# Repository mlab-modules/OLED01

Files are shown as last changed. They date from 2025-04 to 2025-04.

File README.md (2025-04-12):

# OLED01 - OLED Display Touchscreen with I2C interface

The OLED01 is an MLAB module, designed for using OLED displays, specifically the [EA OLEDM128-6GGA](https://www.lcd-module.com/fileadmin/eng/pdf/grafik/oledm128-6e.pdf) built around the [SSD1306](https://cdn-shop.adafruit.com/datasheets/SSD1306.pdf) controller, this module communicates using the I2C protocol. The module's design uses standard MLAB headers and an internal 12V power supply, for powering the OLED display. This  module provides a solution for integrating high-contrast OLED displays into various systems.

An important feature of the OLED01 module is the integrated I2C level converter, which can operate within a 3-5V power supply and signal range. The OLED01 also incorporates a pair of LEDs and a buzzer, driven by an integrated transistor and it is equipped with a reset circuit to ensure proper clear display initialization after power-up.

## Design
OLED01 OLED01

The OLED01 module is designed to promote user-friendly integration and durability. Its compact form factor allows for easy placement within diverse hardware configurations, and the robust construction assures longevity. The contained OLED display delivers a resolution of 128x64 pixels with high-contrast visual output.

### Touchscreen Support

The OLED01 module supports 4-wire resistive touchscreens through integration with the [TSC2007 touch controller](https://www.ti.com/lit/ds/symlink/tsc2007.pdf). This I2C-based controller enables position and pressure detection with 12-bit resolution, low power consumption, and internal preprocessing for noise reduction. The PENIRQ output allows interrupt-based touch event detection.

This expands the module's usability for interactive user interfaces in embedded systems.

## Specifications

- **Interface**: I2C
- **Touchscreen Support**: 4-wire resistive touchscreen interface via TSC2007 (I2C, 12-bit ADC)
- **Power Supply**: 3-5V operational range for I2C, Internal 12V supply for OLED
- **Display**: 128x64 pixels resolution
- **Additional Features**: Pair of LEDs and buzzer driven by integrated transistor by external GPIO
- **Reset Circuit**: Included for proper initialization of the OLED display

## Possible Applications

The OLED01 module's versatility allows for use in a wide range of applications:

2. **Industrial Control Systems:** The robustness and clarity of the OLED display, coupled with the additional buzzer and LED indicators, make this module a top choice for control panels in industrial machinery and robotics.
3. **Automotive Systems:** The OLED01 can serve as an interface for vehicle systems, providing clear and sharp visual output under various lighting conditions.
5. **Experimental Projects and Prototyping:** The module's easy integration through MLAB headers and broad compatibility with the I2C interface make it suitable for experimental electronics projects, prototyping, and educational applications.

## Schematics
Schematics

## Usage examples

  * [Li-ion-Charger](https://github.com/MLAB-project/Li-ion-Charger)

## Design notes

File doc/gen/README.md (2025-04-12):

# PCB

Board size: 60.76x70.92 mm (2.39x2.79 inches)

- This is the size of the rectangle that contains the board
- Thickness: 1.6 mm (63 mils)
- Material: FR4
- Finish: None
- Layers: 2
- Copper thickness: 35 µm

Solder mask: TOP / BOTTOM

- Color: Green

Silk screen: TOP / BOTTOM

- Color: White

Stackup:

| Name | Type | Color | Thickness [µm]| Material | Er | Loss tan |
|---|---|---|---|---|---|---|
| F.SilkS | Top Silk Screen | | | | | |
| F.Paste | Top Solder Paste | | | | | |
| F.Mask | Top Solder Mask | Green | 10 | | | |
| F.Cu | copper | | 35 | | | |
| dielectric 1 | core | | 1510 | FR4 | 4.5 | 0.020 |
| B.Cu | copper | | 35 | | | |
| B.Mask | Bottom Solder Mask | Green | 10 | | | |
| B.Paste | Bottom Solder Paste  | | | | | |
| B.SilkS | Bottom Silk Screen | | | | | |

# Important sizes

Clearance: 0.2 mm (8 mils)

Track width: 0.4 mm (16 mils)

- By design rules: 0.2 mm (8 mils)

Drill: 0.5 mm (20 mils)

- Vias: 0.5 mm (20 mils) [Design: 0.4 mm (16 mils)]
- Pads: 1.0 mm (39 mils)
- The above values are real drill sizes, they add 0.1 mm (4 mils) to plated holes (PTH)

Via: 0.8/0.4 mm (31/16 mils)

- By design rules: 0.4/0.3 mm (16/12 mils)
- Micro via: yes [0.2/0.1 mm (8/4 mils)]
- Buried/blind via: yes
- Total: 54 (thru: 54 buried/blind: 0 micro: 0)

Outer Annular Ring: 0.15 mm (6 mils)

- By design rules: 0.26 mm (10 mils)

Eurocircuits class: 4B
- Using min drill 0.5 mm for an OAR of 0.15 mm

# General stats

Components count: (SMD/THT)

- Top: 0/10 (THT)
- Bottom: 43/1 (SMD + THT)

Defined tracks:

- 0.2 mm (8 mils)
- 0.3 mm (12 mils)
- 0.4 mm (16 mils)
- 0.5 mm (20 mils)

Used tracks:

- 0.4 mm (16 mils) (237) defined: yes
- 0.5 mm (20 mils) (9) defined: yes
- 0.6 mm (24 mils) (24) defined: no
- 1.0 mm (39 mils) (6) defined: no
- 1.1 mm (43 mils) (3) defined: no

Defined vias:

Used vias:

- 0.8/0.4 mm (31/16 mils) (Count: 54, Aspect: 2.0 A) defined: no

Holes (excluding vias):

- 0.89 mm (35 mils) (55)
- 3.0 mm (118 mils) (4)

Oval holes:

Drill tools (including vias and computing adjusts and rounding):

- 0.5 mm (20 mils) (54)
- 1.0 mm (39 mils) (55)
- 3.1 mm (122 mils) (4)

Solder paste stats:

Using a paste with 87.75 % alloy, that has an specific gravity for the alloy of 7.4 g/cm³
and 1.0 g/cm³ for the flux. This paste has an specific gravity of  4.15 g/cm³.

The stencil thickness is  0.12 mm.

| Side | Pads with paste | Area [mm²] | Paste [g] |
|---|---|---|---|
| Total  | 125 | 204.41 | 1.02 |

Note: this is just an approximation to the theoretical value. Margins of the solder mask and waste aren't computed.

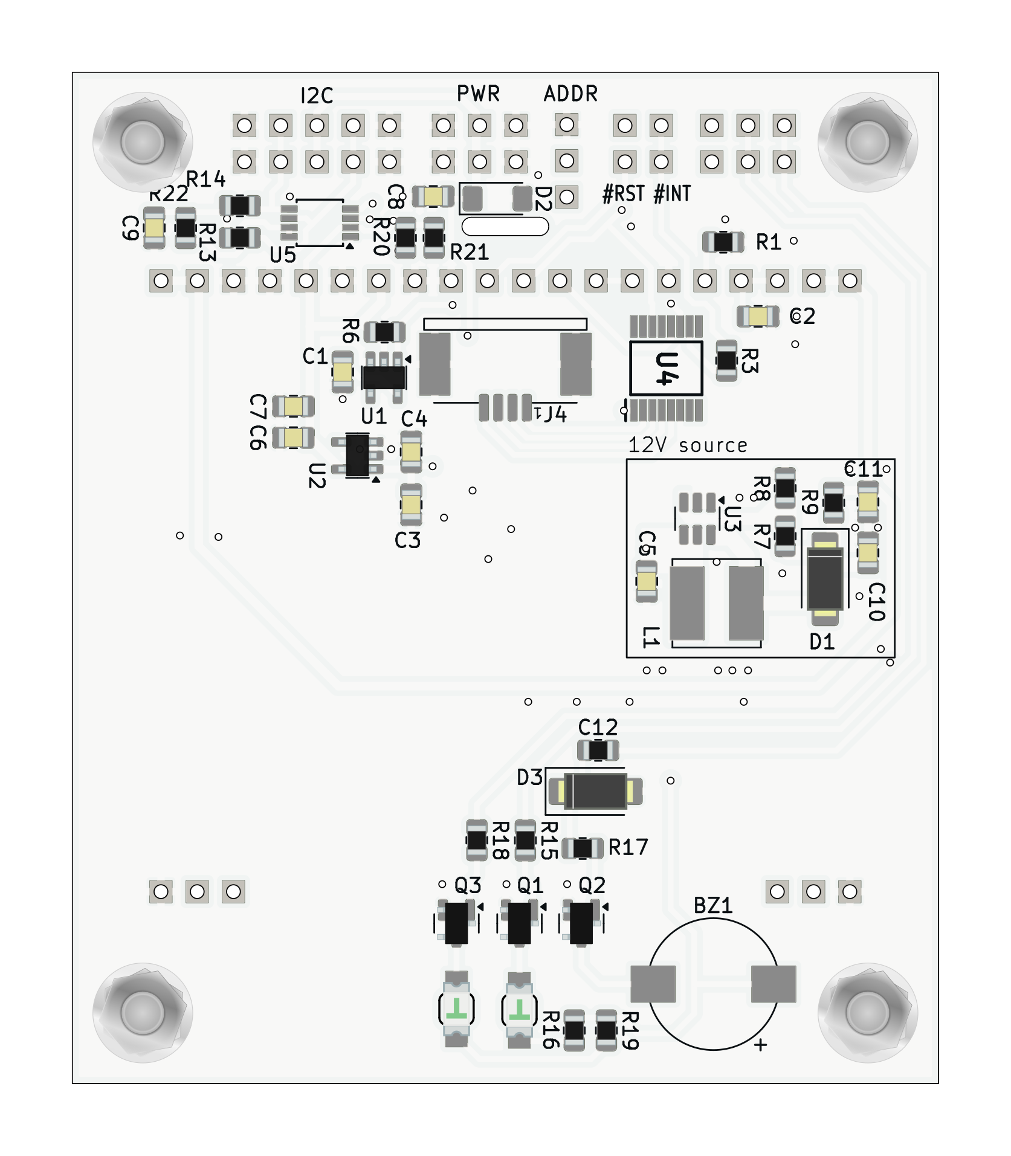
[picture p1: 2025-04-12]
doc/gen/img/OLED01-bottom.png

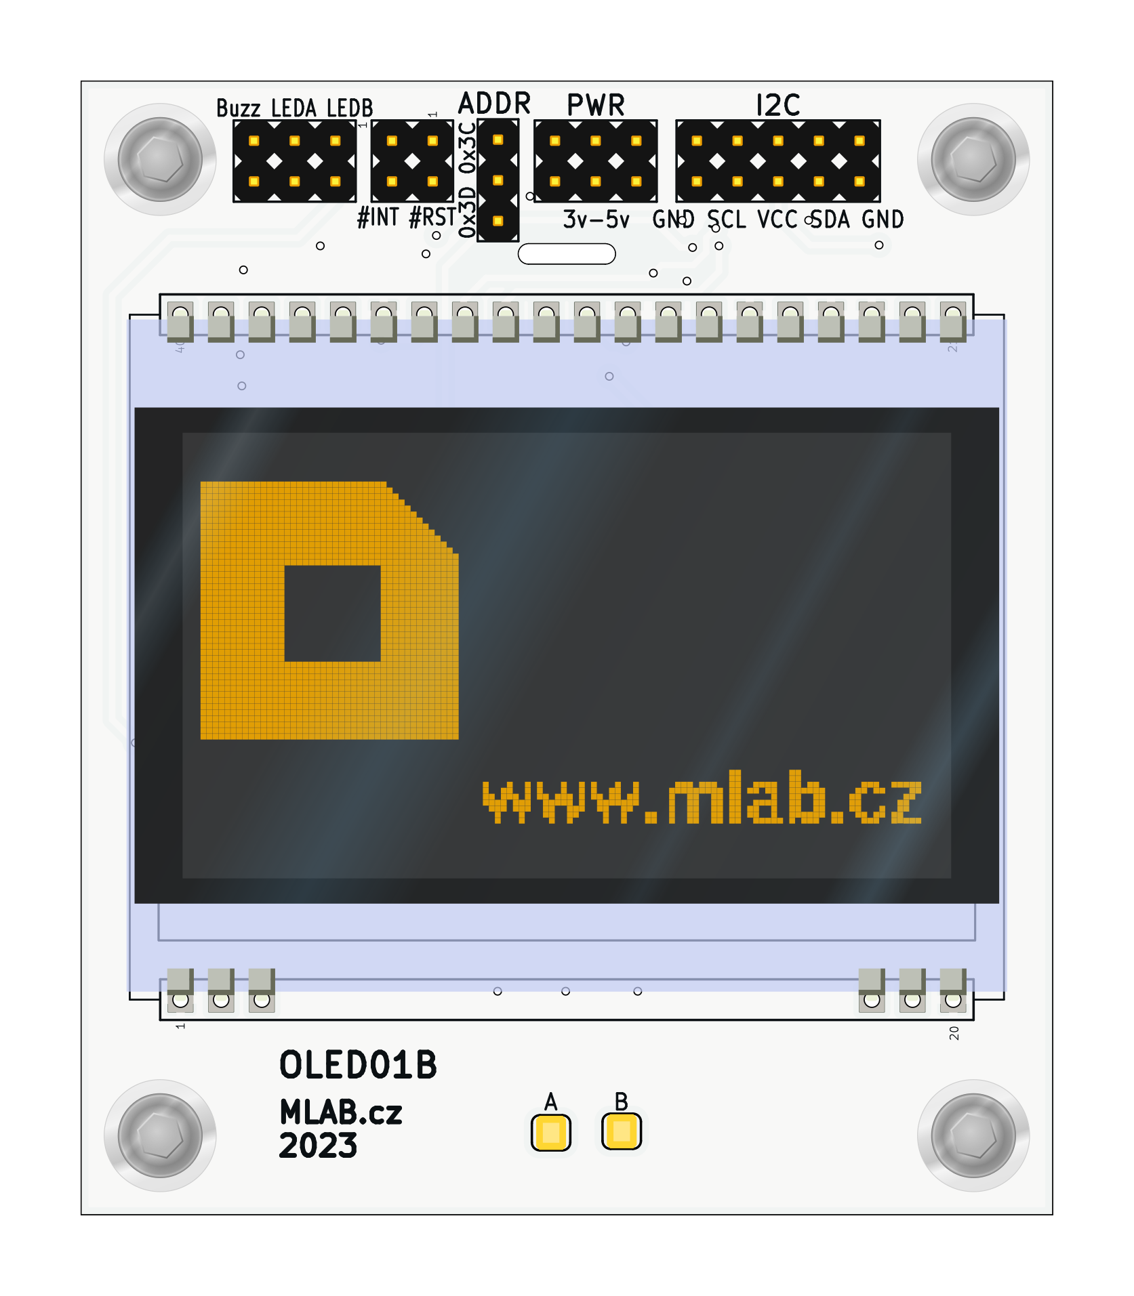
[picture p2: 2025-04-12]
doc/gen/img/OLED01-top.png

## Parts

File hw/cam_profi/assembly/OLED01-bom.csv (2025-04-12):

Component | Description | Part | References | Value | Footprint | Quantity Per PCB | Datasheet | ust_id | manufacturer_name | manufacturer_part_number | mouser part number | mouser price/stock | arrow part number | arrow price/stock
1 | Buzzer, polarized | Buzzer | BZ1 | LET9032ES-03L-2.7-16-R | MagneticBuzzer_LET9032ES-03L-2.7-16-R | 1 | ~ | 5fa0f13812875025b3977890
2 |  | C_Small-Device-ISM02A-rescue | C9 | 100nF | C_0805_2012Metric | 1 |  | C0805_100n
3 |  | C_Small-Device-ISM02A-rescue | C10C11 | 1uF | C_0805_2012Metric | 2 |  | 5c70984712875079b91f8b50
4 | Unpolarized capacitor, small symbol | C_Small | C3C6 | 1uF | C_0805_2012Metric | 2 | ~
5 | Unpolarized capacitor, small symbol | C_Small | C2 | 2.2uF | C_0805_2012Metric | 1 | ~ | 5c70984712875079b91f8b51
6 | Unpolarized capacitor | C | C12 | 10uF | R_0805_2012Metric | 1 | ~ | 5c70984812875079b91f8bbd
7 | Unpolarized capacitor, small symbol | C_Small | C5 | 10uF | C_0805_2012Metric | 1 | ~ | 5c70984812875079b91f8bbe
8 |  | C_Small-Device-ISM02A-rescue | C8 | 10uF | C_0805_2012Metric | 1 |  | 5c70984812875079b91f8bbe
9 | Unpolarized capacitor, small symbol | C_Small | C1C4C7 | C_Small | C_0805_2012Metric | 3 | ~ | 5c70984712875079b91f8b4a
10 | Schottky diode, small symbol | D_Schottky_Small | D1 | 1A 20V 15MQ040N | D_SMA | 1 | ~ | 5c70984512875079b91f88b0
11 |  | D_ZENER-MLAB_D | D2 | BZV55C-5,6V | D_MiniMELF | 1 |  | 5c70984512875079b91f88b2
12 | Light emitting diode | LED | D5 | KPTR-3216CGCK | LED_1206_2 | 1 | ~ | 5c70984512875079b91f8898
13 | Light emitting diode | LED | D4 | KPTR-3216SURCK | LED_1206_2 | 1 | ~ | 5c70984512875079b91f8898
14 | Diode | D | D3 | M4 | D_SMA | 1 | ~ | 5c70984512875079b91f88ac
15 | OLED display, 128x64 px | EA_OLEDM128-6 | DISP1 | EA_OLEDM128-6 | EA_OLEDM128-6GGA | 1 | https://cz.mouser.com/datasheet/2/127/oledm128_6e-1388684.pdf | 628e008ddc56076e9a2237a2
16 | Generic shielded connector, single row, 01x04, script generated (kicad-library-utils/schlib/autogen/connector/) | Conn_01x04_Shielded | J4 | Conn_01x04_Shielded | EA_WF100-04S | 1 | ~
17 | 1x03 2.54 mm pitch header | HEADER_1x03 | J5 | HEADER_1x03 | Straight_1x03 | 1
18 | 2x02 2.54 mm pitch header, 2 pins next to each other are connected | HEADER_2x02_PARALLEL | J3 | HEADER_2x01_PARALLEL | Straight_2x02 | 1
19 | 2x03 2.54 mm pitch header, 2 pins next to each other are connected | HEADER_2x03_PARALLEL | J1J2 | HEADER_2x03_PARALLEL | Straight_2x03 | 2
20 | 2x05 2.54 mm pitch header, 2 pins next to each other are connected | HEADER_2x05_PARALLEL | J6 | HEADER_2x05_PARALLEL | Straight_2x05 | 1
21 | Inductor, small symbol | L_Small | L1 | 4.7uH | L_Bourns_SRN6045TA | 1 | ~ | 5c70984412875079b91f8828
22 | NPN transistor, base/emitter/collector | Q_NPN_BEC | Q1Q2Q3 | BC817-25 | SOT-23 | 3 | ~ | 5c70984712875079b91f8aea
23 | Resistor, small symbol | R_Small | R3 | 33R | R_0805_2012Metric | 1 | ~
24 | Resistor, small symbol | R_Small | R9 | 100R | R_0805_2012Metric | 1 | ~ | 5c70984512875079b91f8977
25 | Resistor, small symbol | R_Small | R17 | 220R | R_0805_2012Metric | 1 | ~ | 5c70984512875079b91f897f
26 | Resistor, small symbol | R_Small | R8 | 8k2 | R_0805_2012Metric | 1 | ~ | 5c70984612875079b91f899c
27 | Resistor, small symbol | R_Small | R6R13R14R20R21 | 10k | R_0805_2012Metric | 5 | ~ | 5c70984612875079b91f899f
28 | Resistor, small symbol | R_Small | R15R18 | 20k | R_0805_2012Metric | 2 | ~ | 5c70984612875079b91f89a3
29 | Resistor, small symbol | R_Small | R7 | 73k2 | R_0805_2012Metric | 1 | ~ | 5cee6226128750448edc1fab
30 | Resistor, small symbol | R_Small | R22 | 200k | R_0805_2012Metric | 1 | ~
31 | Resistor, small symbol | R_Small | R1 | 910k | R_0805_2012Metric | 1 | ~ | 628e00e9dc56076e9a2237ce
32 | Resistor, small symbol | R_Small | R16R19 | R | R_0805_2012Metric | 2 | ~
33 |  | MAX5026 | U3 | MAX5026 | TSOT-23-6 | 1 |  | 5c70984712875079b91f8b7c
34 | 300mA Low-dropout Voltage Regulator, Vout 1.8V, Vin up to 5.5V, SOT-23 | MIC5504-1.8YM5 | U2 | MIC5504-2.5YM5 | SOT-23-5 | 1 | http://ww1.microchip.com/downloads/en/DeviceDoc/MIC550X.pdf
35 | Dual bidirectional I2C Bus and SMBus voltage level translator, TSSOP-8 | PCA9306DP | U5 | PCA9306DP | TSSOP-8_3x3mm_P0.65mm | 1 | https://www.nxp.com/docs/en/data-sheet/PCA9306.pdf
36 | TLV840 Nano-Power Ultra-Low Voltage Supervisor with Adjustable Reset Time Delay | TLV840 | U1 | TLV840 | SOT-23-5 | 1
37 | Touch Screen Controllers Nano-Power w/ I2C Serial Interface | TSC2007IPWG4 | U4 | TSC2007IPWG4 | SOP65P640X120-16N | 1 | https://www.ti.com/lit/ds/symlink/tsc2007.pdf?ts=1606975891024 |  | Texas Instruments | TSC2007IPWG4 | 595-TSC2007IPWG4 | https://www.mouser.co.uk/ProductDetail/Texas-Instruments/TSC2007IPWG4?qs=0OHPnBYoB%2FlCWJNSlSlD9A%3D%3D | TSC2007IPWG4 | https://www.arrow.com/en/products/tsc2007ipwg4/texas-instruments

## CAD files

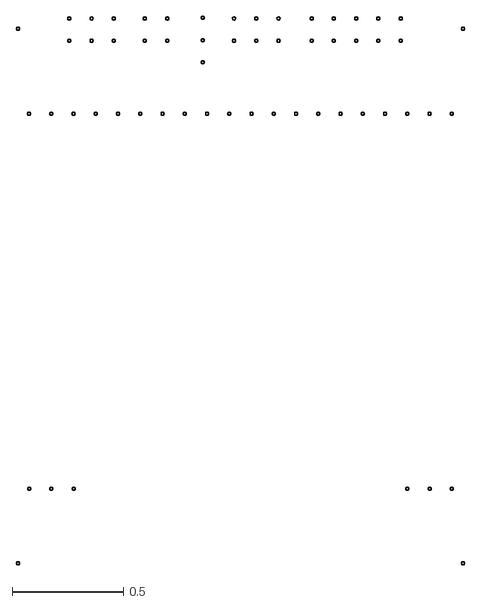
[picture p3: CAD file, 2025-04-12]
doc/gen/dxf/OLED01-Uivatel_2.dxf
2.01 x 2.46

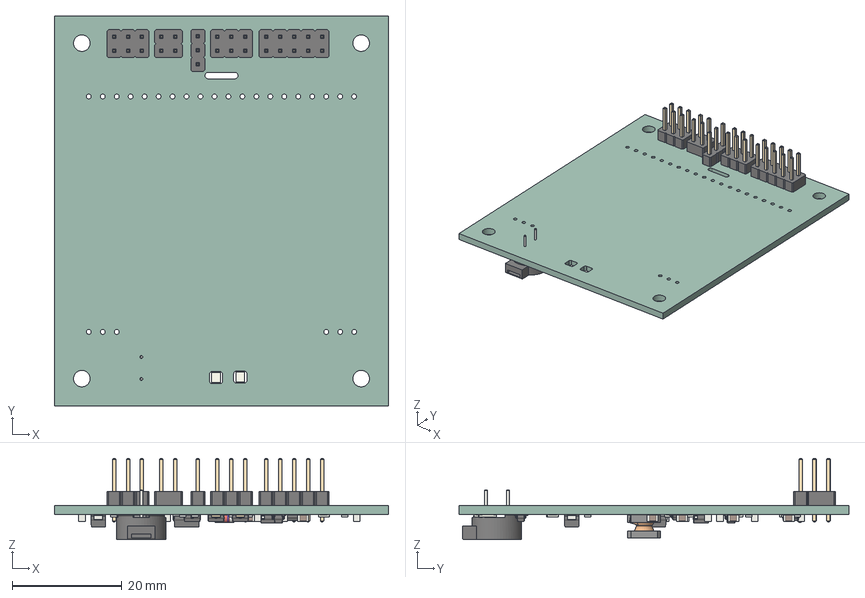
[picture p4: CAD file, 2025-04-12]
doc/gen/OLED01.step
60.8 x 70.9 x 14.8 mm
PinHeader_2x03_P254mm_Vertical x 2
PinHeader_2x05_P254mm_Vertical
PinHeader_1x03_P254mm_Vertical
PinHeader_2x02_P254mm_Vertical
R_0805_2012Metric x 17
L_Bourns_SRN6045TA
TSOT_23_6
SOT_23 x 3
C_0805_2012Metric x 11
D_MiniMELF_Standard
D_SMA x 2
SOT_23_5 x 2
TSSOP_8_3x3mm_P065mm
LED_1206_3216Metric x 2
MagneticBuzzer_CUI_CST_931RP_A
kibot_n7xkv_uf_PCB

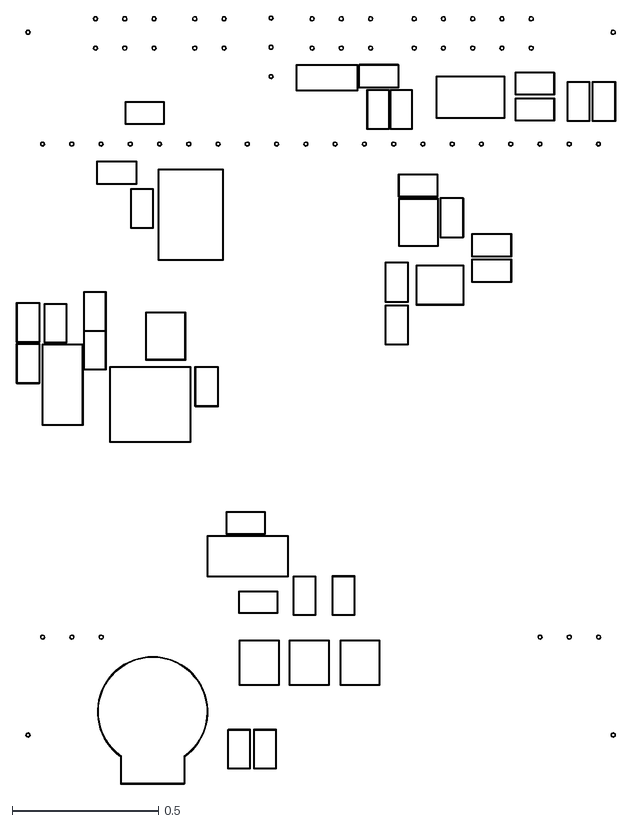
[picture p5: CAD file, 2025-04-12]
doc/gen/dxf/OLED01-B_Courtyard.dxf
2.05 x 2.62

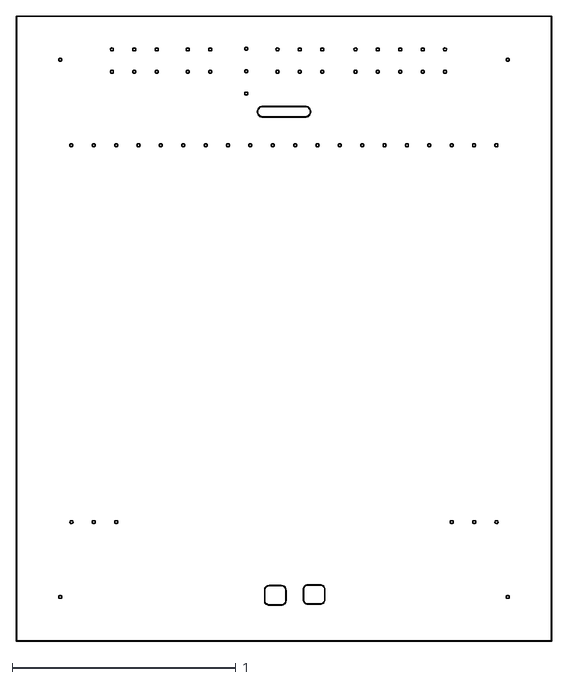
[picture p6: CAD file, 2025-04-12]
doc/gen/dxf/OLED01-Edge_Cuts.dxf
2.39 x 2.79

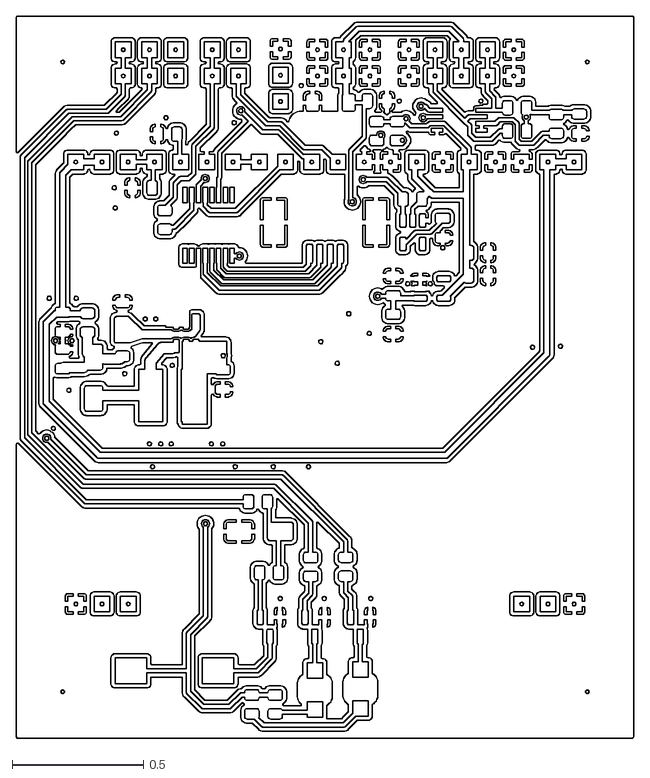
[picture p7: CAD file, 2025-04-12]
doc/gen/dxf/OLED01-B_Cu.dxf
2.35 x 2.75

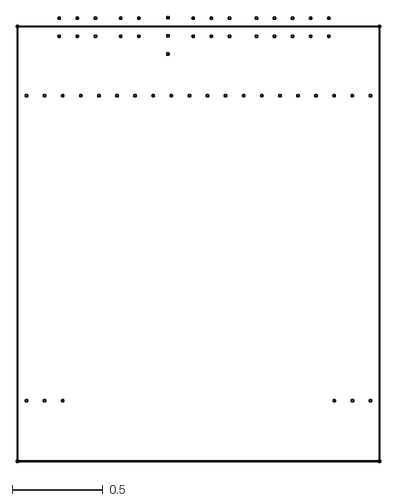
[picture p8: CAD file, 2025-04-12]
doc/gen/dxf/OLED01-User_Drawings.dxf
2.01 x 2.46

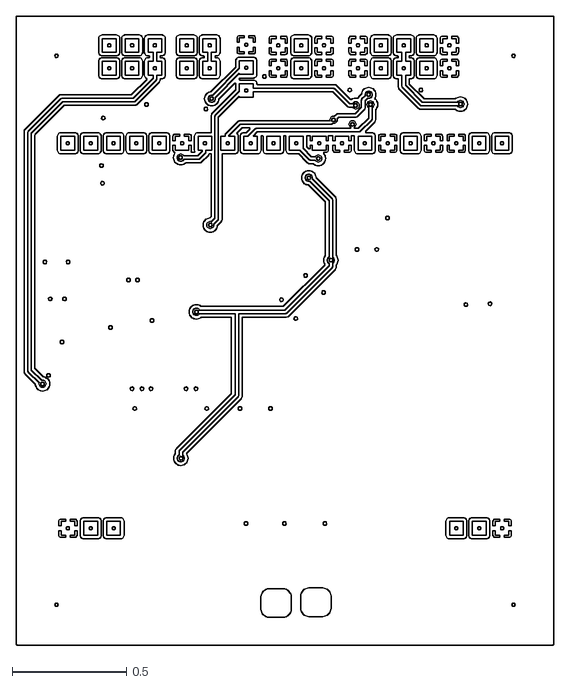
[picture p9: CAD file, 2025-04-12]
doc/gen/dxf/OLED01-F_Cu.dxf
2.35 x 2.75

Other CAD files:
doc/gen/dxf/OLED01-B_Adhesive.dxf
doc/gen/dxf/OLED01-B_Fab.dxf
doc/gen/dxf/OLED01-B_Mask.dxf
doc/gen/dxf/OLED01-B_Paste.dxf
doc/gen/dxf/OLED01-B_Silkscreen.dxf
doc/gen/dxf/OLED01-F_Adhesive.dxf
doc/gen/dxf/OLED01-F_Fab.dxf
doc/gen/dxf/OLED01-F_Mask.dxf
doc/gen/dxf/OLED01-F_Paste.dxf
doc/gen/dxf/OLED01-F_Silkscreen.dxf

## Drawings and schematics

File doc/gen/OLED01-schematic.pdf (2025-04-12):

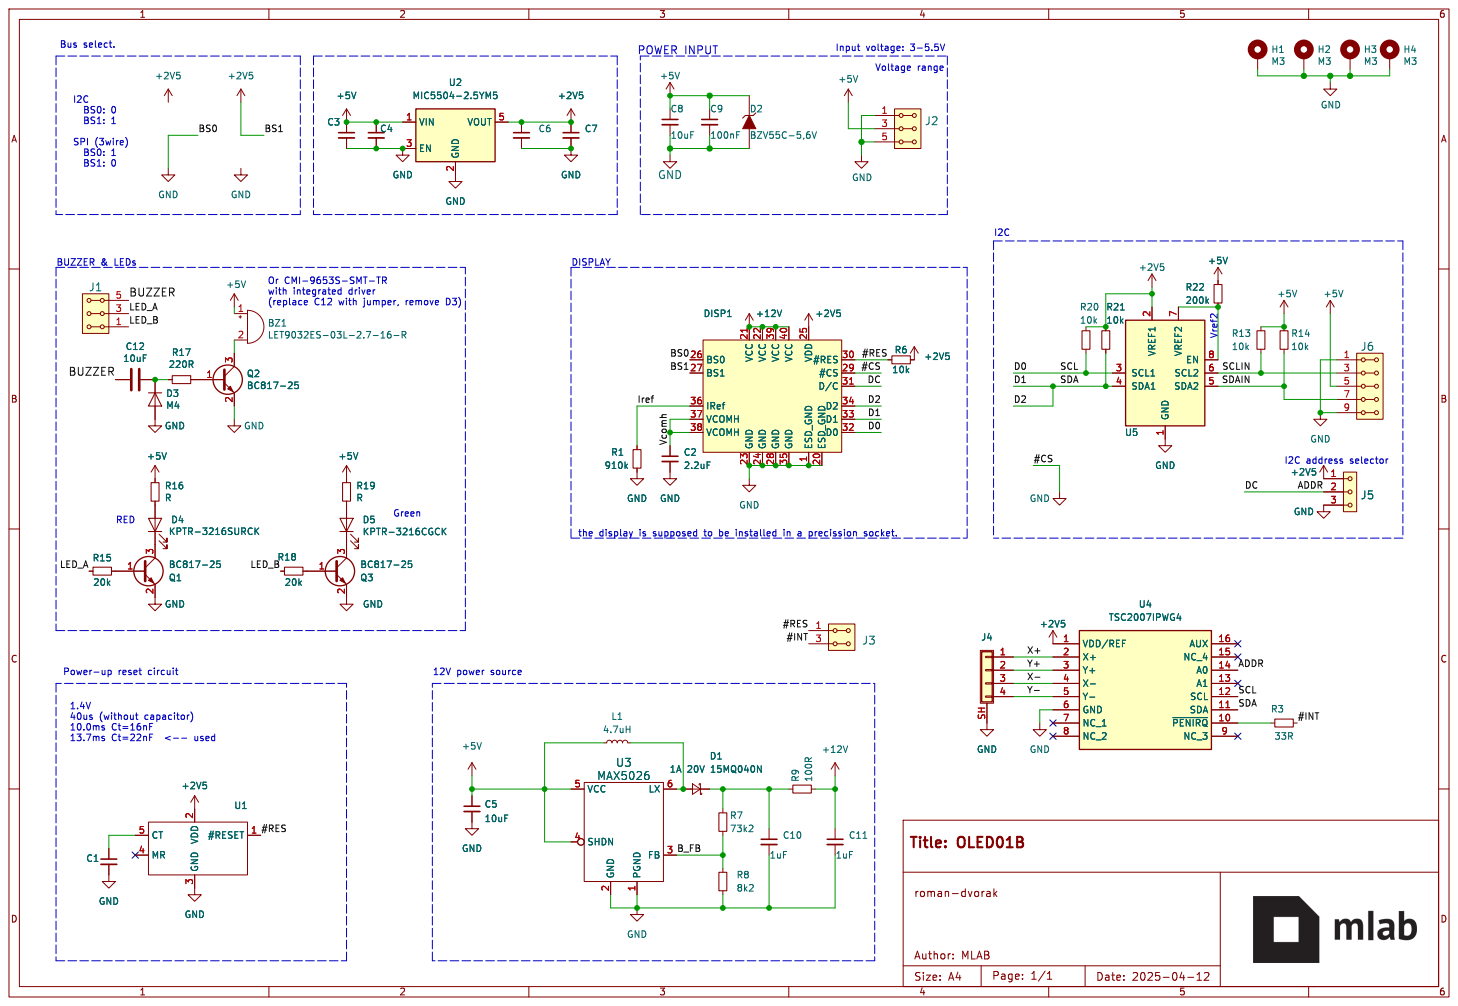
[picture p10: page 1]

2 EN 3 VOUT 5 U2 MIC5504-2.5YM5 GND GND

2 EN 3 VOUT 5 GND GND

I2C Or CMI-9653S-SMT-TR

1 ESD_GND 20 VCC 21 VCC 22 GND 23 GND 24 VDD 25 BS0 26 BS1 27 GND 28

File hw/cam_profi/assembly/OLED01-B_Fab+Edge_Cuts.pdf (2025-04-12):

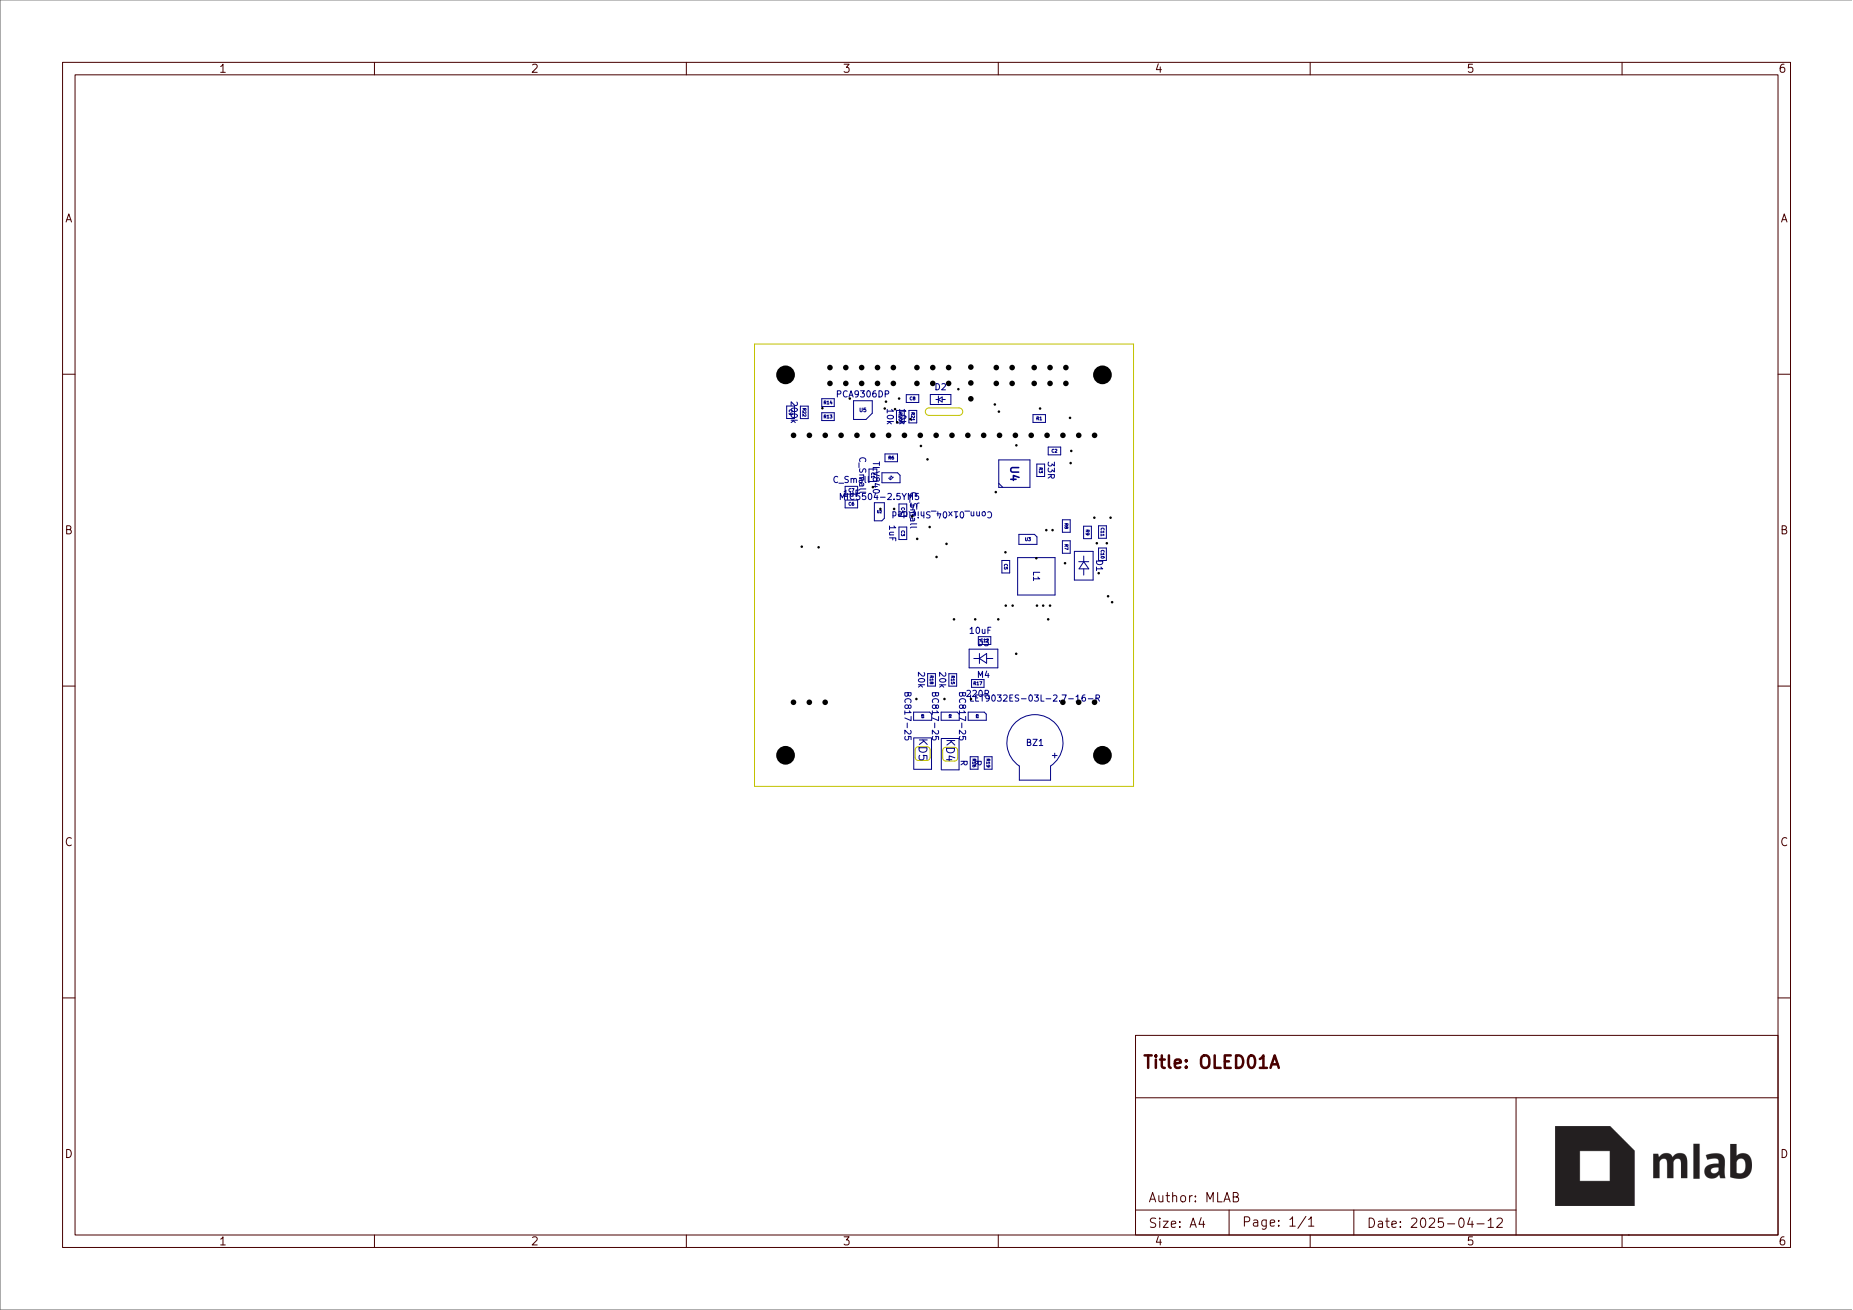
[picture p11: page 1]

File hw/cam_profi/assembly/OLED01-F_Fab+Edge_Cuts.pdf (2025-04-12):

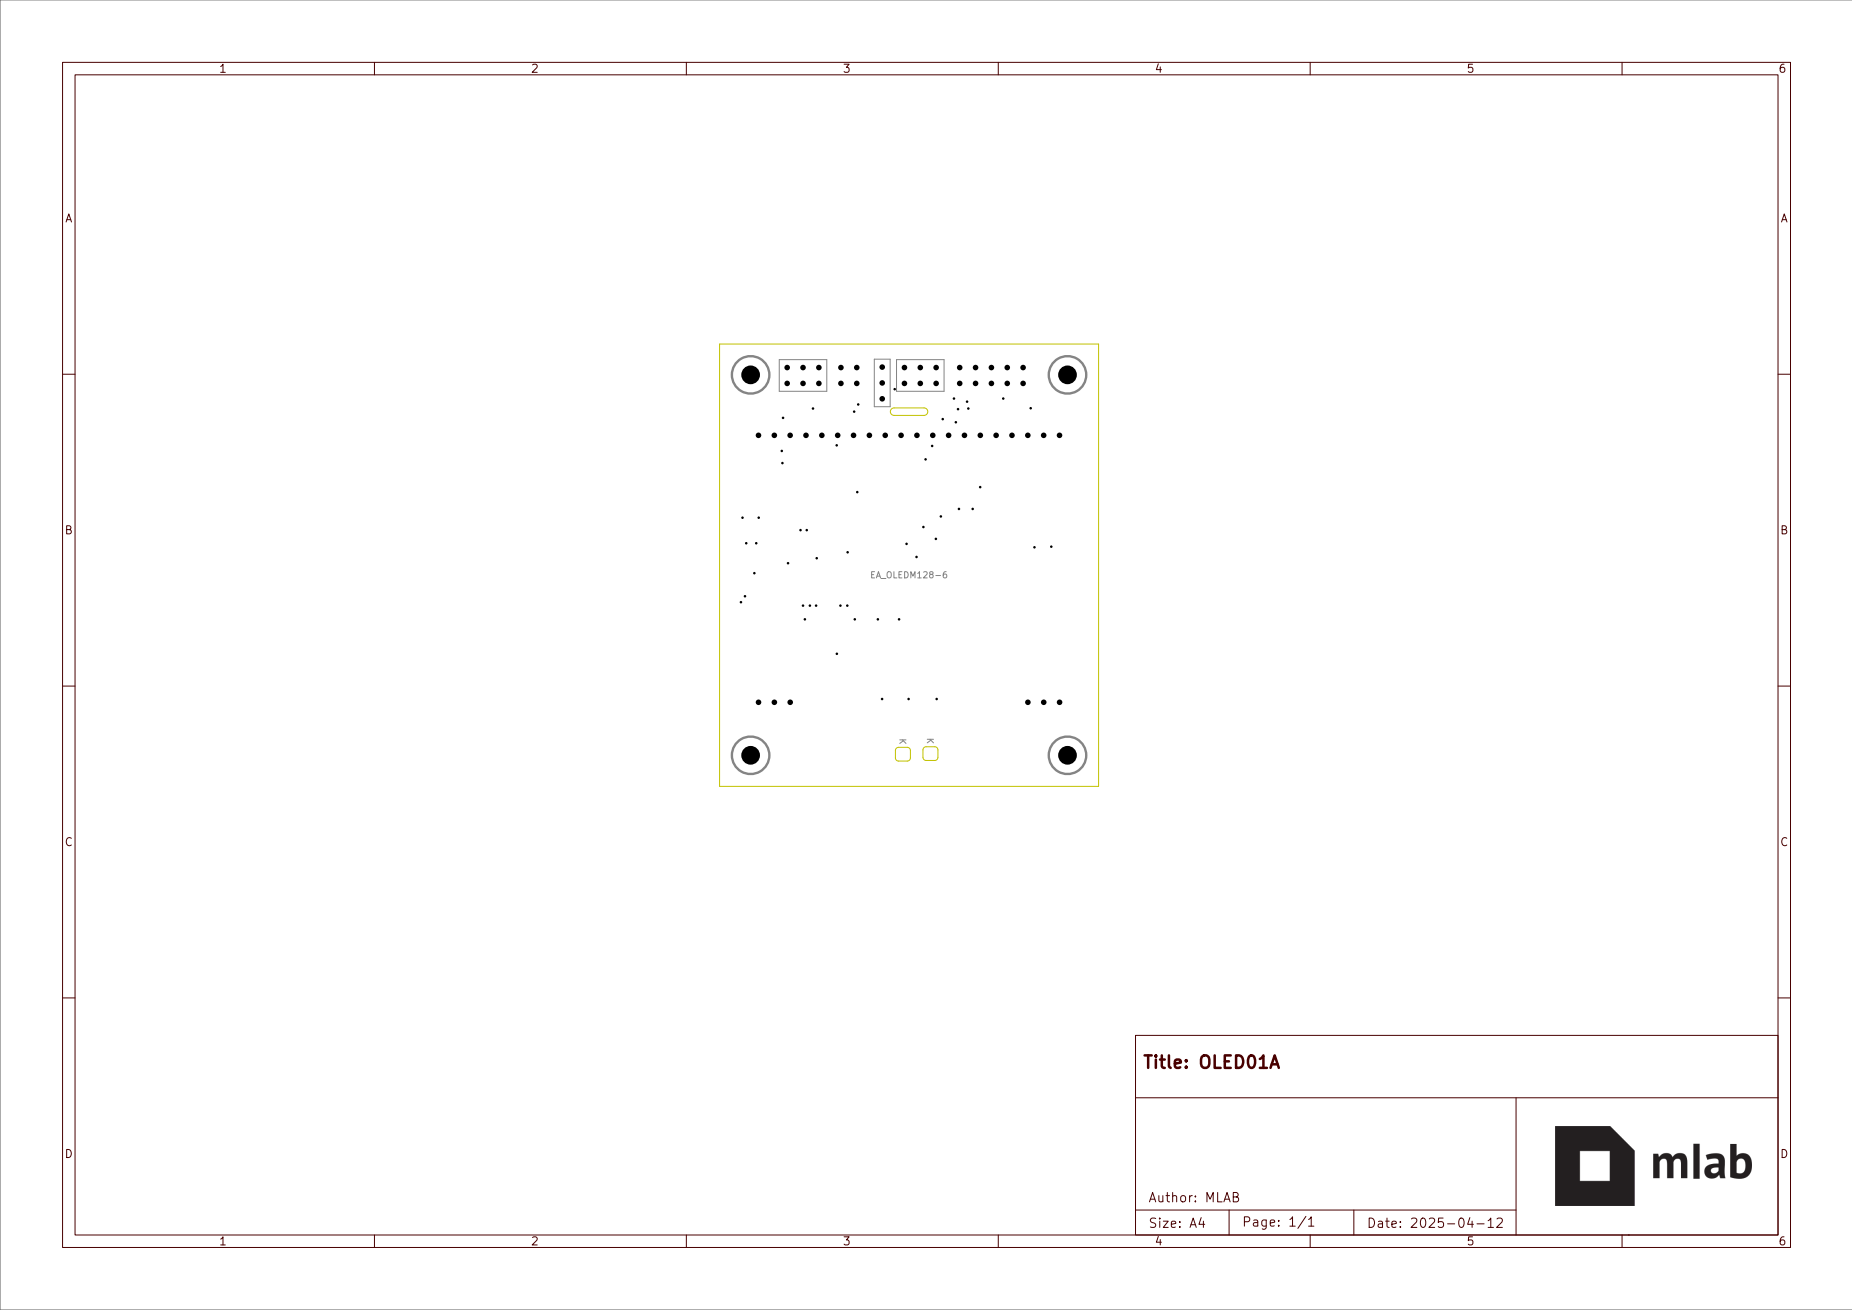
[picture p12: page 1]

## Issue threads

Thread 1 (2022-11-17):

Silkscreen Top

kaklik, 2022-11-17:
U I2C konektoru je překlep. Místo SCL je CLK.

roman-dvorak, 2022-11-21:
Na nabíječce je [Li-ion charger](https://github.com/ODZ-UJF-AV-CR/Li-ion-Charger) je display používán obráceně (o 180 deg) než bylo při návrhu zamýšleno. Je nutné zjistit, jestli je to chyba umístění displaye/popisků. Nebo jestli je to věc konkrétního použití displaye a jak je složité obraz otočit.

Bylo to zamýšleno tak, aby kablíky vedly "nad" displayem a nepřekážely v pohledu. Zároveň aby bylo možné display umístit na svislo a hřebínek osadit reverzně.

Closed 2023-06-14.

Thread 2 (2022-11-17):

Low impedance at SCL and SDA signals

kaklik, 2022-11-17:
Vypadá to že I2C signály displeje mají nízkou impedanci.

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

Bylo by tak zřejmě vhodné k displeji přidat nějaký buffer, který zajistí, že I2C sběrnice nebude displejem příliš zatěžovaná.

roman-dvorak, 2022-11-21:
Tohle by mohlo vyřešit 2 problémy zároveň. Kdyby to nebyl prostý buffer, ale nějaký převodník úrovní a LDO na cca 2.5V (tak, aby to zvládalo napájení z 3V a zároveň aby to bylo v provozním rozsahu displaye) tak by se mohl zvýšit rozsah napájecího napětí i na 5V I2C. Čímž, by se zase zvětšila užitnost tohoto displaye. Tak, aby provozní rozsah napájení byl 3V - 5.5V Není to částé, ale stále se dnes lze setkat s 5V napájením/i2c.

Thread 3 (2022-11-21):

Display reset

kaklik, 2022-11-21:
Podle datasheetu displej pro správnou funkci vyžaduje RESET po náběhu napájení. Používání displeje bez tohoto resetu vedlo k zobrazení "šumu" nebo "rozsypaného čaje" na displeji.

Reset je tak potřeba ovládat, zároveň je velmi nepraktické, aby bylo potřeba k displeji připojovat vice jak celkem čtyři vodiče pro I²C.
Reset by proto chtělo ošetřit přímo na modulu. Jsou na to dvě možnosti, buď použít i2c buffer #2 , který ošetří i reset a nebo nějaký resetovací obvod kontrolující napájení.

roman-dvorak, 2022-11-21:
Ještě jedno z možných řešení by bylo displej vybavit nějakým I2C GPIO, který by bylo možné ovládat nezávisle na stavu napájení. Ale nějaký resetovací obvod od TI je elegantní řešení problému. Tyto přístupy by však bylo možné zkombinovat.

roman-dvorak, 2022-11-21:
V kombinaci s mým návrhem (https://github.com/mlab-modules/OLED01/issues/2#issuecomment-1321881911) na použití LDO pro rozšíření provozních rozsahů a I2C převodníku úrovní by bylo možné použít pro reset tento obvod:
https://cz.mouser.com/ProductDetail/Texas-Instruments/TLV840CADL28DBVR?qs=DPoM0jnrROVqu9kM%252BZsXvQ%3D%3D

Je koupitelný a jeho zapojení je velmi jednoduché.

kaklik, 2022-11-23:
> Ještě jedno z možných řešení by bylo displej vybavit nějakým I2C GPIO, který by bylo možné ovládat nezávisle na stavu napájení. Ale nějaký resetovací obvod od TI je elegantní řešení problému. Tyto přístupy by však bylo možné zkombinovat.

Pokud by tam mělo být GPIO, tak dává smysl to zkombinovat s obsluhou touchscreenu #5  Měl by to umět například tenhle obvod. [STMPE610](https://www.st.com/en/touch-and-display-controllers/stmpe610.html), akorát že je zrovna obsolete.

roman-dvorak, 2025-03-13:
Reset pomoci GPIO je zde asi komplikace, protože je potřeba přes I2C ovládat další součástku. A dostupné arduino knihovny s tím nepočítají. Když bude v B revizi touchscreen, tak by bylo dobré, aby to šlo použít i bez touchscreenu a tedy i bez osazené "obslužné GPIO" součástky.

V OLED02 je stejný požadavek na restart po zapnutí napájení. Vypadá to, že tento resetovací obvod je dostatečný:
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

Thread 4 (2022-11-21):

Inverted font on display compared to silkscreen

kaklik, 2022-11-21:
Na zařízení https://github.com/ODZ-UJF-AV-CR/Li-ion-Charger vznikla situace že text na displeji je vzhůru nohama oproti popiskům na PCB. Je potřeba zjistit proč se to stalo a zda s tím budeme něco dělat.

roman-dvorak, 2022-11-21:
V dokumentaci je displej všude zobrazen v této orientaci
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

Což odpovídá aktuálnímu silkscreenu.

Pro změnu orientace je zřejmě nutné zapnout remapped režim:
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

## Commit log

2022-05-12 prvni verze
    [OLED01A.kicad_pcb, OLED01A.kicad_sch]
2022-05-12 change path
    [OLED01A.kicad_pcb, OLED01A.kicad_sch]
2022-05-12 uprava pcb
    [OLED01A.kicad_pcb]
2022-05-15 Uprava layoutu, silkscreen
    [OLED01A.kicad_pcb, OLED01A.kicad_sch]
2022-05-15 Update actions products
    [OLED01A-B_Adhesive.dxf, OLED01A-B_Courtyard.dxf, OLED01A-B_Cu.dxf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]
2022-05-15 pullup na reset pin
    [OLED01A.kicad_pcb, OLED01A.kicad_sch]
2022-05-16 Zmena menice, oprava DRC
    [OLED01A.kicad_pcb, OLED01A.kicad_sch]
2022-05-16 Oprava layoutu
    [OLED01A.kicad_pcb]
2022-05-16 Edit silkscreen
    [OLED01A.kicad_pcb]
2022-05-16 Zvětšení potisku
    [OLED01A.kicad_pcb]
2022-05-16 update silkscreen
    [OLED01A.kicad_pcb]
2022-05-16 Pridani USTID
    [OLED01A.kicad_sch]
2022-05-21 Edit PCB
    [OLED01A.kicad_pcb]
2022-05-25 Příprava dat pro osazení.
    [OLED01A.kicad_pcb, OLED01A.kicad_sch]
2022-07-18 uprava id soucastek
    [OLED01A.kicad_sch]
2022-07-18 Pridani poznamky o predpokladane montazi
    [OLED01A.kicad_sch]
2022-08-11 Oprava UST ID
    [OLED01A.kicad_sch]
2022-11-22 rename source files
    [OLED01B.kicad_pcb, OLED01B.kicad_sch]
2022-11-23 Update schematics
    [OLED01B.kicad_pcb, OLED01B.kicad_sch]
2022-12-17 add LDO type, fill packages, pcb placement
    [OLED01B.kicad_pcb, OLED01B.kicad_sch]
2023-02-12 aktualizace actions, kicad rename
    [OLED01.kicad_pcb, OLED01.kicad_sch]
2023-06-13 Update schematics, add reset circuit, route pcb
    [OLED01.kicad_pcb, OLED01.kicad_sch]
2023-06-14 update assets
    [OLED01.kicad_sch]
2023-06-14 repair hole
    [OLED01.kicad_pcb]
2023-06-14 i2c level convertor
    [OLED01.kicad_pcb, OLED01.kicad_sch]
2023-06-14 update schematics, layout, improve silkscreen
    [OLED01.kicad_pcb, OLED01.kicad_sch]
2023-06-15 solve DRC
    [OLED01.kicad_pcb, OLED01.kicad_sch]
2025-04-12 Update project and workflow to KiCADv8. Improvements in the PCB layout. Documentation update.
    [OLED01.kicad_pcb, OLED01.kicad_sch]
